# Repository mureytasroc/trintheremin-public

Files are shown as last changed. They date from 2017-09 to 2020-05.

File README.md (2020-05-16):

# TrinTheremin (Version 1)
***




---
#### Important Notes -- Read Before Use
* The minimum case material that the board should have when being played or programmed is the top panel.   After you sodder on the sliders use bolts (provided) to secure the top panel (provided for Advanced CS1) onto the board.   Then when you are using the board hold it by the top laser cut panel, not by the board.

* This version (and all versions) are best used with a full case and horn (see the [case folder](Case) and the [horn folder](Horn) ) for ergonomics and sound quality, though the case and horn are not necessary for basic use.

* The circuit will not work properly if the battery is depleted (see [battery section](#battery) below).   If you have been using the same battery for a while or the circuit is acting like it is low on battery (see [battery section](#battery) below), then follow the instructions in the [battery section](#battery) of this readme to measure how much battery is left.   In future versions there will be an onboard battery sensor you can access in your code.

* The board behaves like an Arduino Micro.   See the "Programming" section below.

* When programming the slider to control the volume of the speaker, map your analog reading from 0-1000 to 0-10.   If you use 0-1023 the full volume tones will sound distorted because it will flicker between volume level 9 and 10.

* See the [example code](#example-code-notes) section of this readme on how to conduct the board calibration.

* See the [expanded documentation](#expanded-documentation) for more information on the board as well as expanded procedures and notes.

---
### Expanded Documentation
---
#### About the Circuit
TrinTheremin, like the Sparkfun <a href="https://www.youtube.com/watch?v=2zZkeeQr49g" target="_blank">Digital Sandboxes</a> used in CS1/CS2, is an all in one programmable <a href="https://learn.sparkfun.com/tutorials/what-is-a-circuit" target="_blank">circuit</a> that allows the user to process/control different inputs/outputs on the board.   Its <a href="http://www.atmel.com/Images/Atmel-7766-8-bit-AVR-ATmega16U4-32U4_Datasheet.pdf" target="_blank">ATMEGA microcontroller chip</a> has its own CPU (central processing unit; the brain of the device), flash memory (where your program is stored), SRAM (where the sketch creates and manipulates variables while running), and <a href="http://tronixstuff.com/2011/03/16/tutorial-your-arduinos-inbuilt-eeprom/" target="_blank">EEPROM</a> (NON-VOLATILE storage space programmers can access/use; EEPROM will keep its stored data even without electrical power (when the unit is off), as opposed to volatile memory (like SRAM) that would lose its data without electrical power).   While you probably won't need to use any EEPROM for this project (although feel free to <a href="https://learn.adafruit.com/memories-of-an-arduino/eeprom" target="_blank">do</a> so if you have a use for it), you will constantly be using the CPU and SRAM, as well as the flash memory (where your program lives).   See this chart for how much memory the microcontroller on the TrinTheremin (the ATMEGA 32u4) has of each main type (there are other memory types onboard that I won't go into):

| Memory Type:  | Amount of storage (bytes): |
| --- | --- |
| Flash  | 32000  |
| SRAM  | 2500  |
| EEPROM  | 1000  |

The flash is not all available, however, as the board's "bootloader" (the software that allows you to upload Arduino code) takes up about 4kB, or 4000 bytes, leaving about 28kB usable for storing code.   The bootloader is already installed on all the boards.

Beyond the chip (and its dedicated hardware such as its crystal and resistors and capacitors), all the circuits on this board should be pretty familiar (with the exception of the speaker's circuit).   See the <a href="https://github.com/TrinitySchoolComputerScience/TrinTheremin/tree/master/Circuit%20Design/Design%20Pictures" target="_blank">circuit design pictures</a> folder.   On the <a href="https://github.com/TrinitySchoolComputerScience/TrinTheremin/tree/master/Circuit%20Design/Design%20Pictures/Schematic/Close%20Ups/Left%20Side%20(Arduino)" target="_blank">left side</a> of the schematic is all the dedicated Arduino hardware, however the <a href="https://github.com/TrinitySchoolComputerScience/TrinTheremin/tree/master/Circuit%20Design/Design%20Pictures/Schematic/Close%20Ups/Right%20Side%20(Peripherals)" target="_blank">right side</a> shows the circuits for all the peripherals (the buttons, switch, light sensor, LEDs, etc).   Take a look at the right side to see how simple (and common) the circuits behind the peripherals are.   The circuit for for the switch, for instance, just includes the switch and a <a href="https://playground.arduino.cc/CommonTopics/PullUpDownResistor" target="_blank">pulldown resistor</a> (which keeps the voltage at 0V unless the switch is closed to 5V) and is connected to a digital pin (D12):

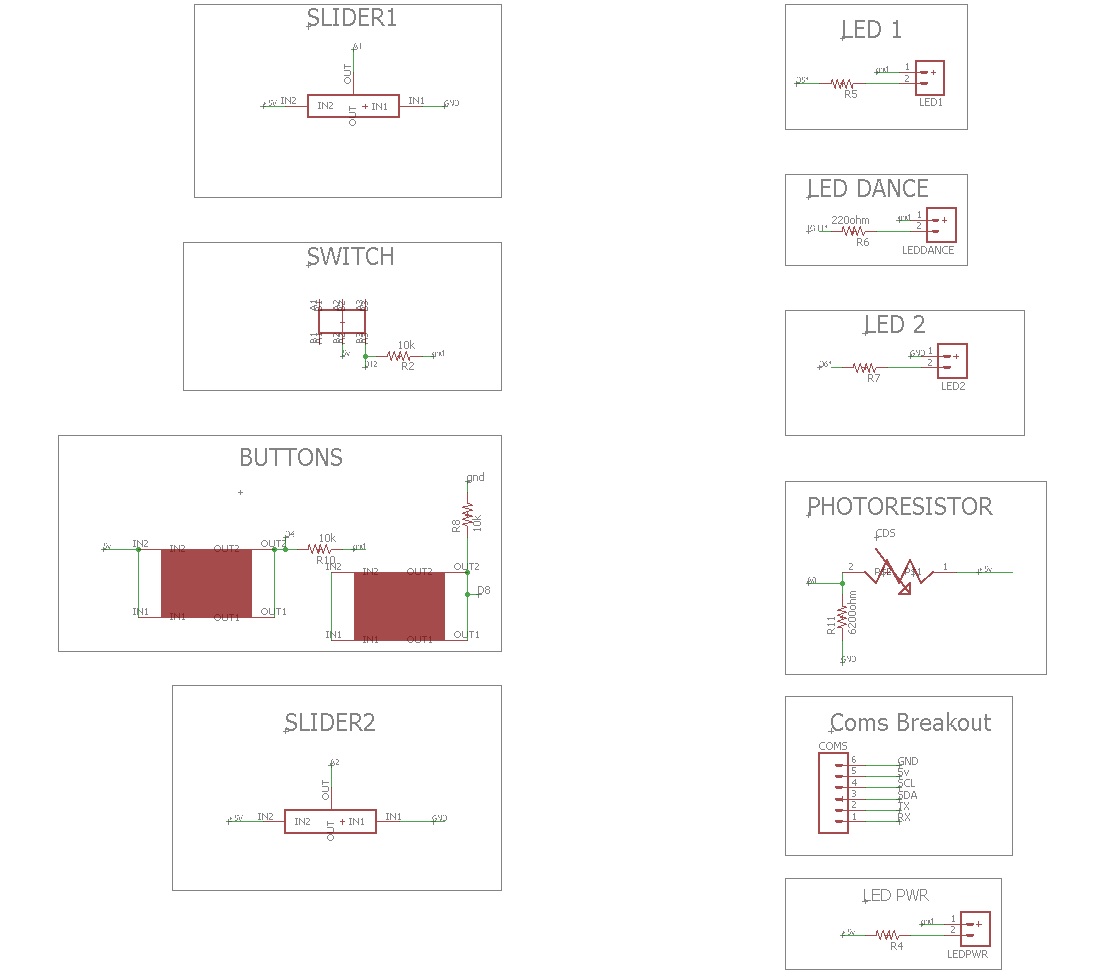
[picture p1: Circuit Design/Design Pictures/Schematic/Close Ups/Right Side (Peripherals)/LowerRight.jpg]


---

#### Usage
The TrinTheremin was purpose built for Trinity's CS2 and Advanced CS1 programs (specifically the physical computing and digital logic units, respectively), although it could be used in a wide variety of applications that use inputs and outputs involving sound and light.

###### Battery
The TrinTheremin's battery should be connected to the 9v battery connector on the bottom of the board and stored in the clip under the slider (also on the bottom of the board).  



Like any device, the TrinTheremin will eventually run out of battery.   Trinity's collection of Apex batteries have a 595mAh capacity.   Milliamp hours (mAh) are a unit of electrical charge (one milliamp hour is about 3.6 coulombs, a unit commonly taught in Trinity physics that is generally used when working with static electricity rather than circuits).   This means that the batteries can supply 595 mA of current for one hour. The TrinTheremin draws about 400 mA when the speaker is on at full volume so at minimum the TrinTheremin will run for about 1.5 hours (with everything running and its speaker on at full volume) continuously.   If you do not have the speaker on the device draws only about 25 mA, which will yield about a day of continuous use (so do not feel the need to turn off the device while programming it as having it on does not use up much battery life) To more accurately determine how much battery life the device has left (and without keeping track of how much time you have used it for), you can measure the remaining battery life with a multimeter (located in the top drawer in the drawers by the door in the computer science lab -- ask Mr. Rose or Mr. Gohde if you are unsure where this is) and a few quick calculations.



First, set the multimeter to measure DC voltage and make sure the leads are connected to the right ports (red to positive (+) and black to negative (-, sometimes referred to as COM) -- see this <a href="https://learn.sparkfun.com/tutorials/how-to-use-a-multimeter" target="_blank">tutorial on multimeters</a>.   Then measure the voltage of the battery (touching the red lead of the multimeter to the positive terminal of the battery (marked by the + symbol on the battery) and the black lead to the negative terminal (marked by the -).   Here is a chart that shows the battery life estimates for an alkaline cell:

| Alkaline Voltage Level and Range (V):  | Usability: |
| --- | --- |
| 1.50  | New and unused  |
| 1.35 – 1.49  | Good  |
| 1.20 – 1.34  | Average  |
| 1.10 – 1.19  | Low  |
| 0.90 – 1.09  | Very Low  |
| < 0.90  | Dead – Discard!  |

Given that alkaline 9v batteries (Trinity's Apex 9v batteries are alkaline) are 6 alkaline cells, we can multiply through these ranges to find voltages that apply to the reading from the 9v battery:

| 9v Battery Voltage Level and Range (V):  | Usability: |
| --- | --- |
| 9  | New and unused  |
| 8.1 – 8.94  | Good  |
| 7.2 – 8.04  | Average  |
| 6.6 – 7.14  | Low (Unusuable below about 6.75v)|
| 5.4 – 6.54  | Very Low (Unusable)|
| < 5.4  | Dead – Discard! (Unusable)|

There is one more factor to consider, though, and that is that the TrinTheremin needs about 6.75v to run properly.   This is because the voltage regulator (a chip on the board that takes the voltage being supplied by the battery and regulates it at a constant 5v for the circuit to use) needs at least 6.75v to be able to output 5v as its supposed to.   This extra 1.75 volts it needs is called the "dropout voltage" -- this chart from the chip's <a href="http://www.st.com/content/ccc/resource/technical/document/datasheet/41/4f/b3/b0/12/d4/47/88/CD00000444.pdf/files/CD00000444.pdf/jcr:content/translations/en.CD0000044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" target="_blank">datasheet</a> was how I found that the dropout voltage is 1.75 volts (assuming 25C temperature and 500mA current draw):



If the board is acting weird or blatantly executing programming commands incorrectly (that's not because of mistakes in the code) it is almost certainly because its does not have the necessary voltage (so measure it and replace the battery if necessary). There is a small range of voltages where the board will turn on but may work improperly.   

###### Programming
The TrinTheremin has the same chip as an <a href="https://store.arduino.cc/usa/arduino-micro">Arduino Micro</a>, so it will behave almost identically to that board.   Important caveats to note:
* When using Serial (rx/tx) on the "COM breakout" you must use Serial1 instead of Serial.   Since this chip has its own embedded usb circuit, Serial.print will print to the Arduino console as usual, however Serial1 will reference the hardware serial ports (rx/tx). So you would use Serial1.begin(9600), Serial1.print("text"), etc to use the HARDWARE serial.   On an Arduino Uno, for example, which has an external USB circuit that is connected inline with the hardware serial ports, the Serial command references both the hardware and the usb serial (so Serial.print will output serial on the tx port but also print to the Arduino developer's console)

* Because the chip has built in USB, when you plug it into your computer it will be recognized as a mouse or keyboard (and you can actually use it as such -- more on that <a href="https://www.arduino.cc/en/Reference/MouseKeyboard">here</a>).

* When you upload your code, select "Arduino Micro" under boards, and the appropriate port under ports.

-----

###### Example Code Notes

* When programming the slider to control the volume of the speaker, map your analog reading from 0-1000 to 0-10.   If you use 0-1023 the full volume tones will sound distorted because it will flicker between volume level 9 and 10.

* The calibration procedure in the example code is this: 
  i. When one LED is blinking do not cover the sensor at all -- it is measuring the ambient light levels; 
  ii. Once the speaker makes a noise and the LED stops blinking cover the sensor with your hand
  iii. Once both LEDs stop blinking and then light up in a pattern the calibration process is complete

* The autoplay feature can work very well if you put your hand over the dancing LED and the sensor.   It will work fine if you leave it in ambient light, but the more ambient light there is, the worse it will work (this cannot be fixed in calibration -- think about it like the LED's light is getting drowned out).

* The toneAc library is used to control the speaker.   To download toneAc see this <a href="https://bitbucket.org/teckel12/arduino-toneac/wiki/Home">link</a>.   Here is the toneAc <a href="https://playground.arduino.cc/Code/ToneAC">reference</a>.

-------
#### Plans for future versions
If any future versions of the TrinTheremin are produced these are some of the goals that did not get included in this initial version:

* _A more efficient amplifier_ -- the amplifier circuit on the TrinTheremin right now is very simple to use and understand (both in software and in hardware), works with the ToneAC library, and has pretty good quality sound (meeting the goals of the board).   However in future versions a more sophisticated amplifier circuit might be combined with a possible TrinTheremin Arduino library to keep the software simplicity of ToneAC while improving quality and GREATLY improving efficiency (battery life would be improved immensely).

* _A voltage divider circuit_ -- this is one of the easiest (and also most helpful) changes that could be introduced in future versions.   Essentially this would take the voltage of the battery, divide it in two (9v becomes 4.5, 7 becomes 3.5, etc), and feed it to an analog input (0v-5v yields a 0-1023 reading) on the microcontroller.   This would allow the programmer to measure the voltage of the battery.   With this they could create an integrated battery life check that would alert the user if the battery were low.

* _Headphone jack_ -- a headphone jack could be added to the board in addition to the speaker so the user could play with headphones on.   The port would have a switch in it that would be conencted to a digital pin so the programmer could automatically turn off the speaker when headphones are plugged in.

* _Reduced cost_ -- right now the TrinTheremin costs about 25$ per board to produce, however with hardware changes and different production methods, this could potentially be significantly reduced.   For reference an Arduino Micro costs about 22$ (with no inputs or outputs built in)

* _Expanded documentation and a more seamless user interface -- maybe a website?_ -- Right now trintherem.in redirects to this github repository, however in the future a website dedicated to the TrinTheremin could be produced.

----

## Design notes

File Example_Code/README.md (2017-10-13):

# Using the TrinTheremin

## Basic Steps
1. **Plug the board into a USB port**. If you want to use the TrinTheremin on battery power: plug in a battery (see home page readme), and turn it on with the power switch.
2. **Calibrate the TrinTheremin**. When the unit first turns on, hold the board normally to allow the sensor to read the ambient light level.   Once the board makes a sound, place your hand over the sensor so it can read a low value.   When the two LEDs stop blinking and flicker the calibration is complete.
3. **Play the TrinTheremin**. Be sure to avoid touching the underside of the board. The amplifier cicuit for the speaker can get hot.

## Learning Activities
1. Experiment with the other switches, sliders, buttons, and LED's on the TrinTheremin. What is the purpose of each? Hand-draw a diagram of the top of the TrinTheremin. 
   - Label all of the TrinTheremin components used for input/output.

2. Examine the code contained in *TrinThereminExampleCode.ino*. This is the code that controls the behavior of the TrinTheremin. It is written in the Arduino programming language because the TrinTheremin essentially embeds an Arduino Micro into a custom circuit board. 
   - Label each component on your hand-drawn diagram with both the pin number and identifier name given to it in *TrinThereminExampleCode.ino*

3. Add two octaves of F Major as a new scale.
   - First, add F Major by replacing the G scale.
   - Then, add back the G scale and incorporate F Major as a fifth option.
   
4. Find the Circuit Design picture of the BoardTop and the BoardBottom.
   - What do the green markings indicate?
   - What do the red markings indicate?
   - What do the white markings indicate?
   - What do the blue markings indicate?

To-Do:
--------------
- Pure max/min for calibration

- Quantized playing (for the non-sequential note problem)

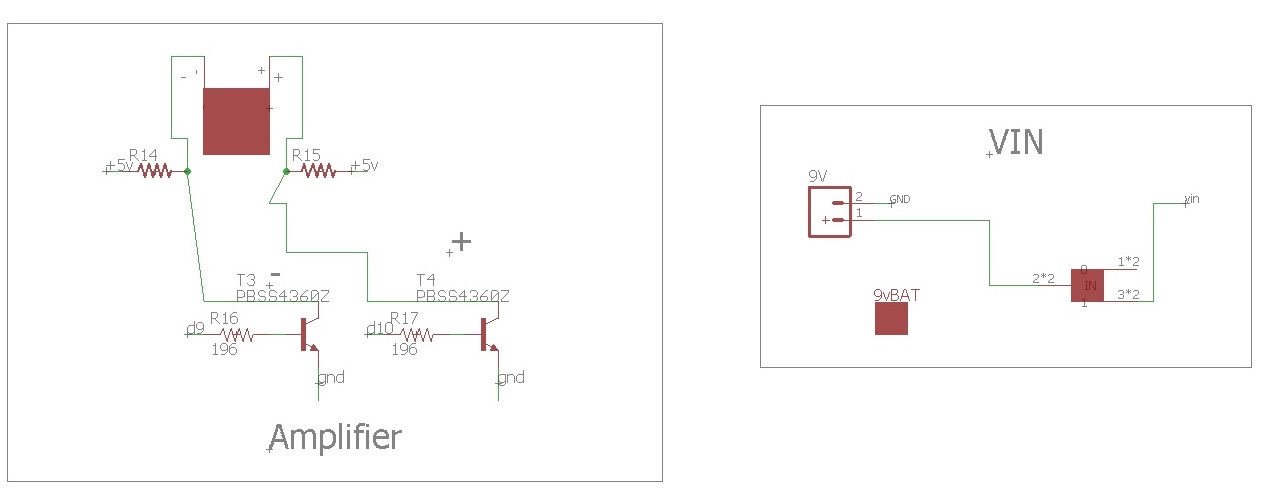
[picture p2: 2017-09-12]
Circuit_Design/Design Pictures/Schematic/Close Ups/Right Side (Peripherals)/UpperRight.jpg

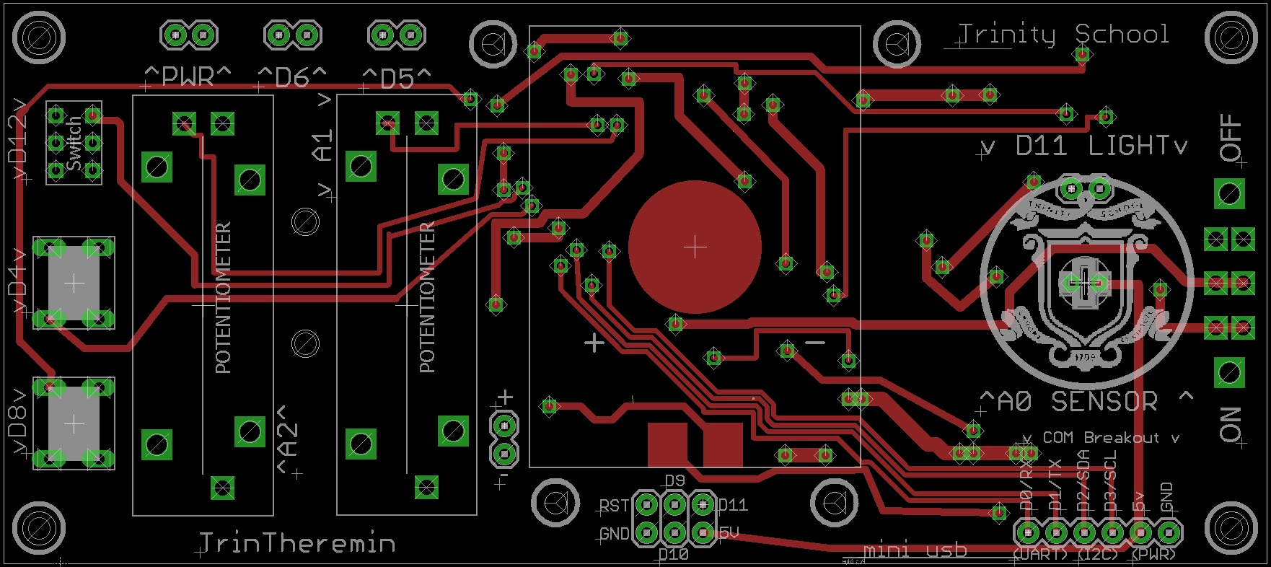
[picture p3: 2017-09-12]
Circuit_Design/Design Pictures/Board/BoardTop.jpg

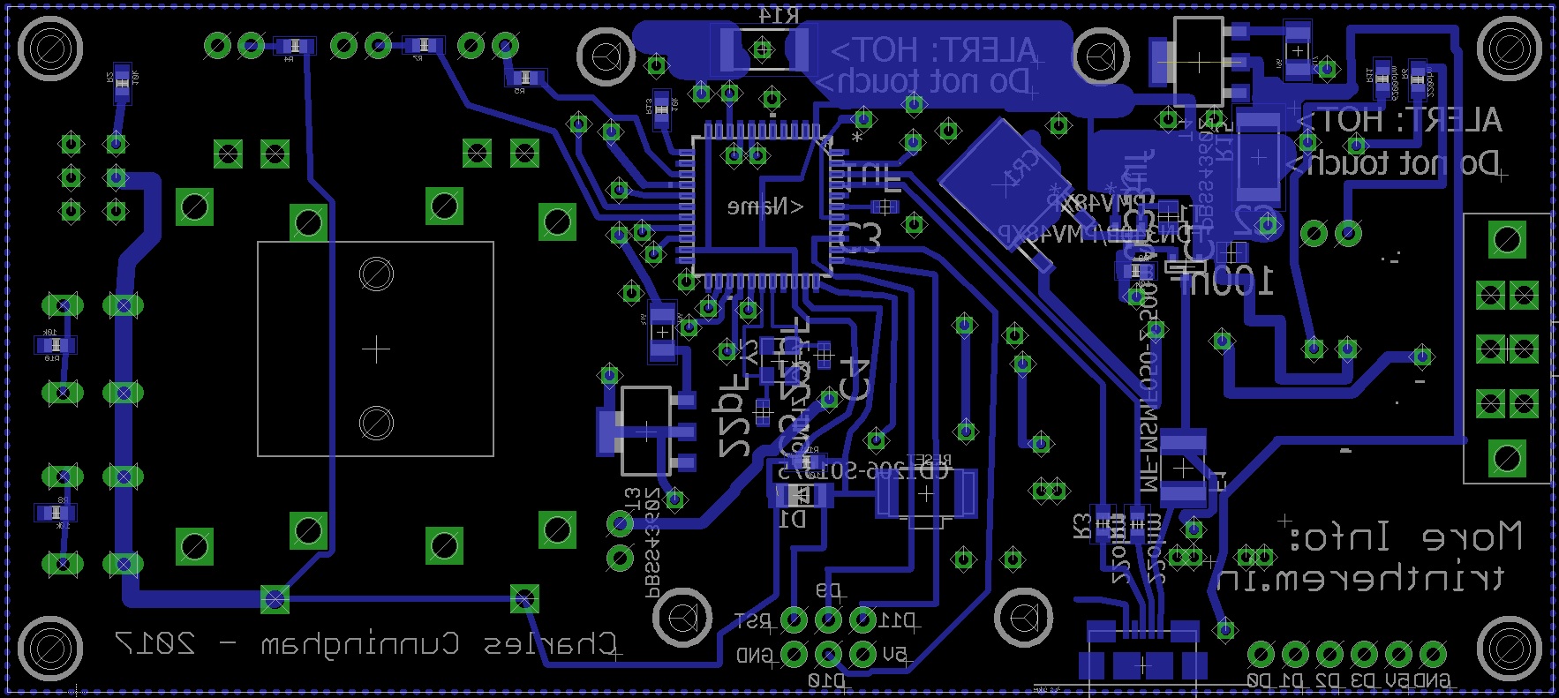
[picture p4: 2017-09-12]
Circuit_Design/Design Pictures/Board/BoardBottom.jpg

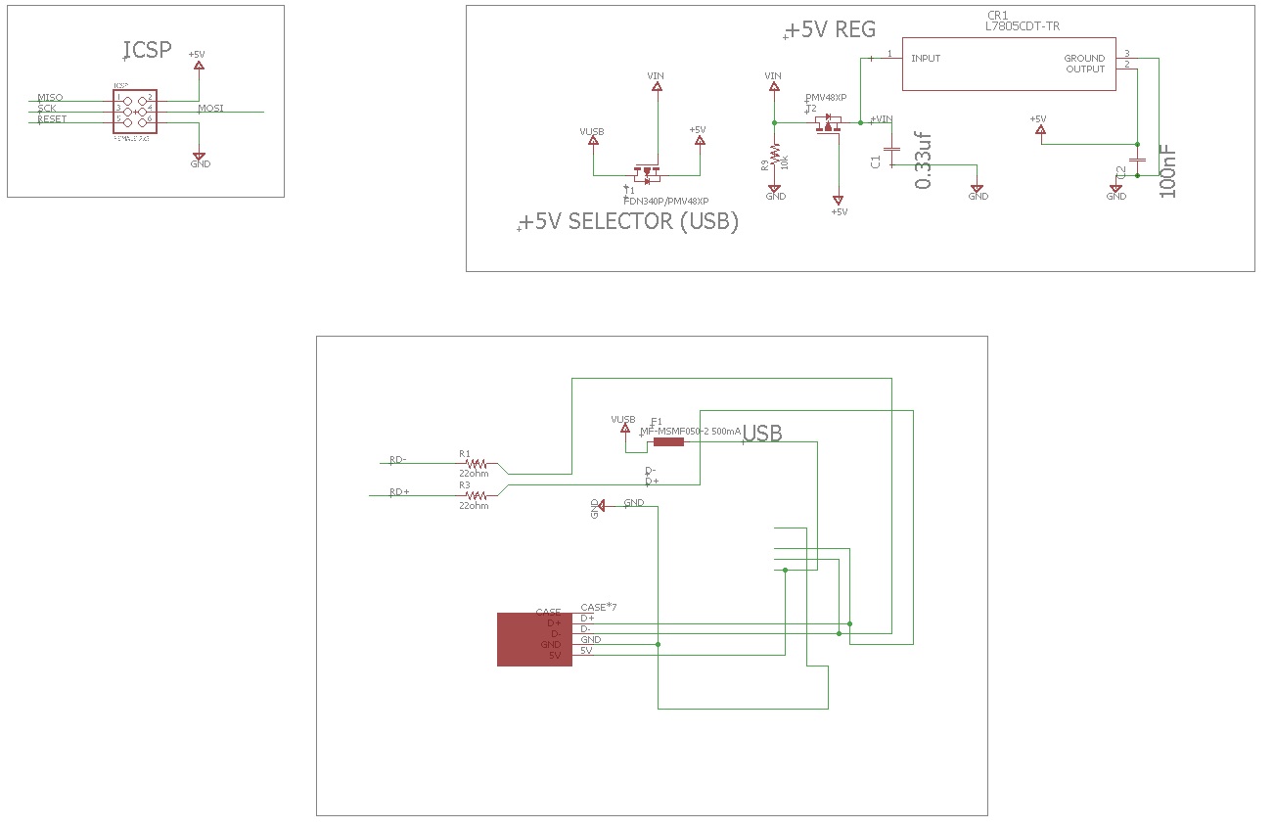
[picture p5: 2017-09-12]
Circuit_Design/Design Pictures/Schematic/Close Ups/Left Side (Arduino)/LowerLeft.jpg

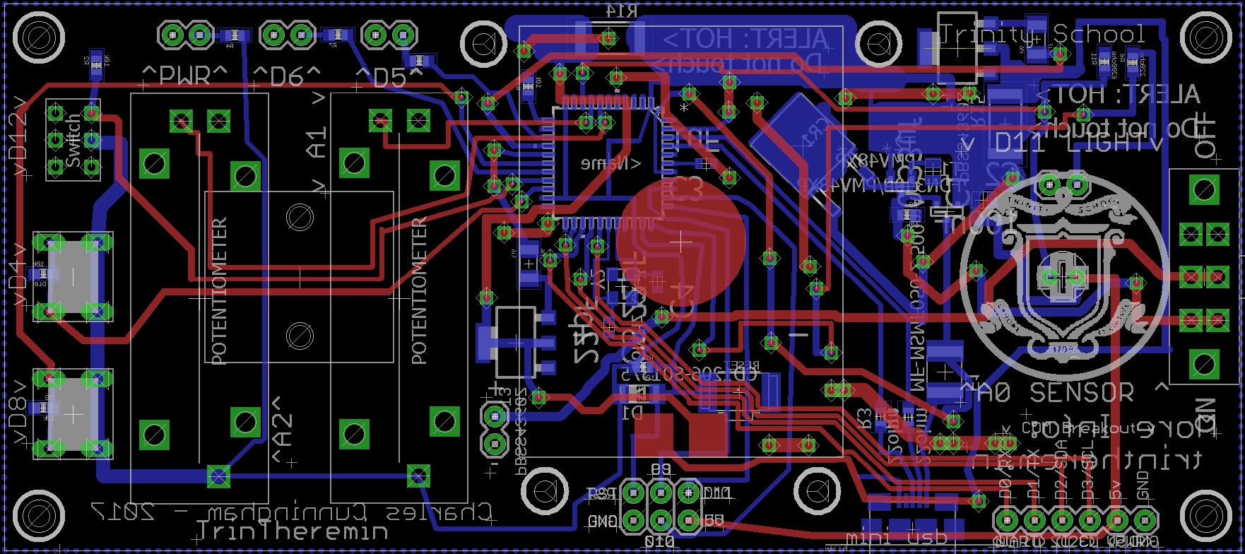
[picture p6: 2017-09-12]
Circuit_Design/Design Pictures/Board/BoardFull.jpg

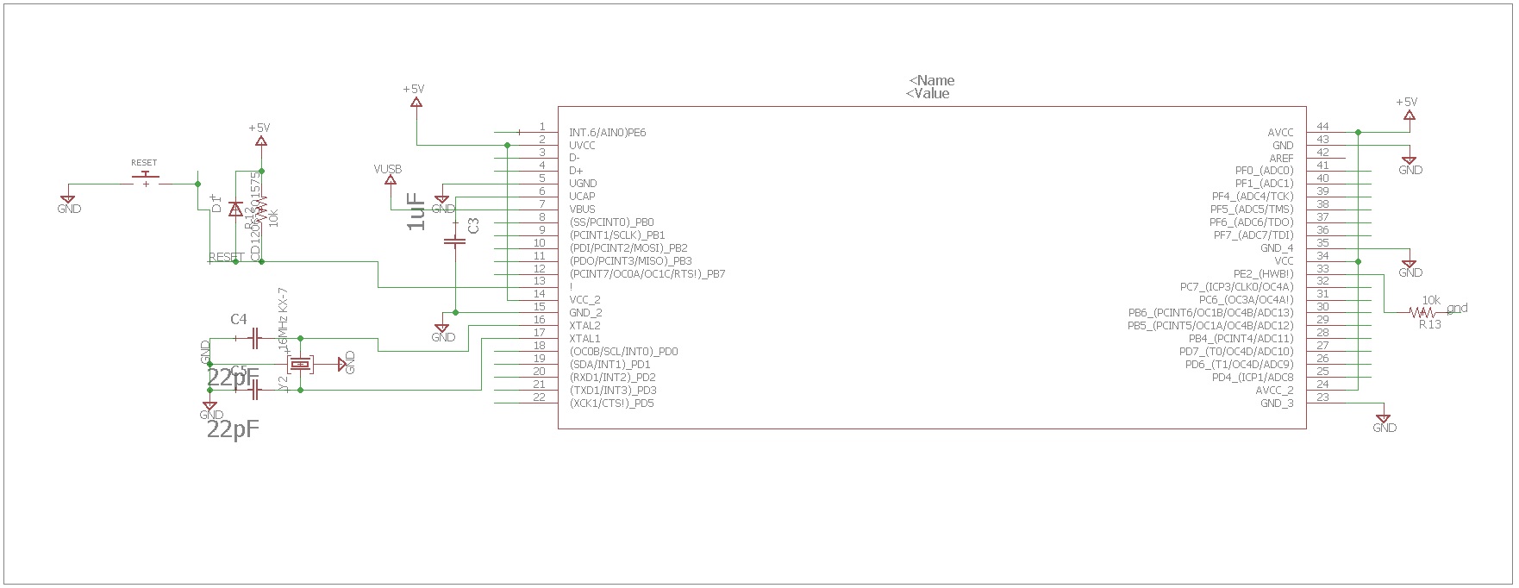
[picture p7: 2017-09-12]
Circuit_Design/Design Pictures/Schematic/Close Ups/Left Side (Arduino)/UpperLeft.jpg

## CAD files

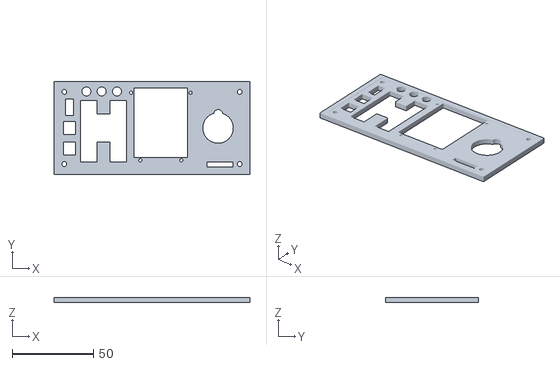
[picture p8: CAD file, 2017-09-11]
Case/3D Design Files/Case STL (3D Models)/CaseTopExample.STL
120.6 x 57.1 x 3.30

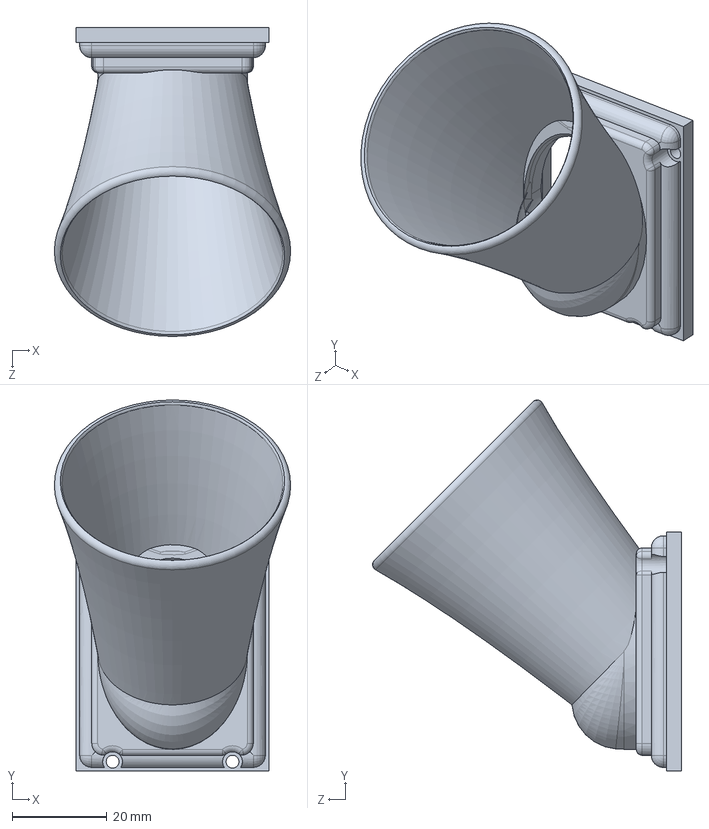
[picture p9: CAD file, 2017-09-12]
Horn/Solidworks/Example/HornExampleMK1.SLDPRT
49.8 x 78.1 x 65.1 mm

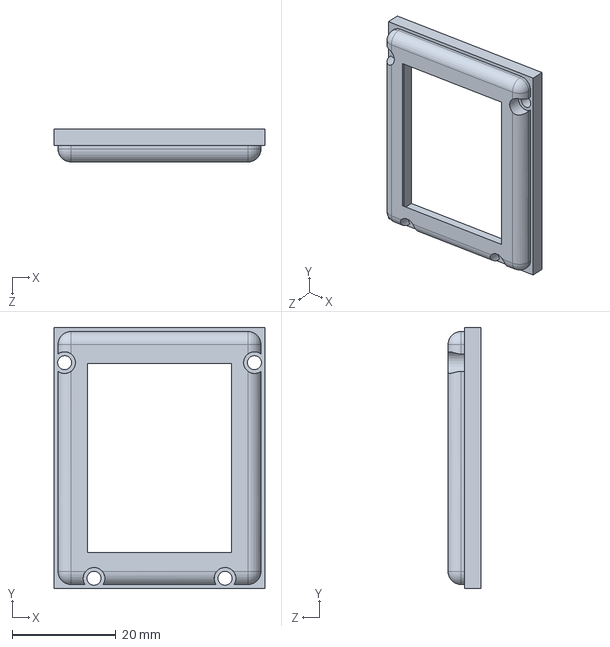
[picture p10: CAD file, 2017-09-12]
Horn/Solidworks/Horn Base/HornBase.SLDPRT
40.6 x 50.3 x 6.35 mm

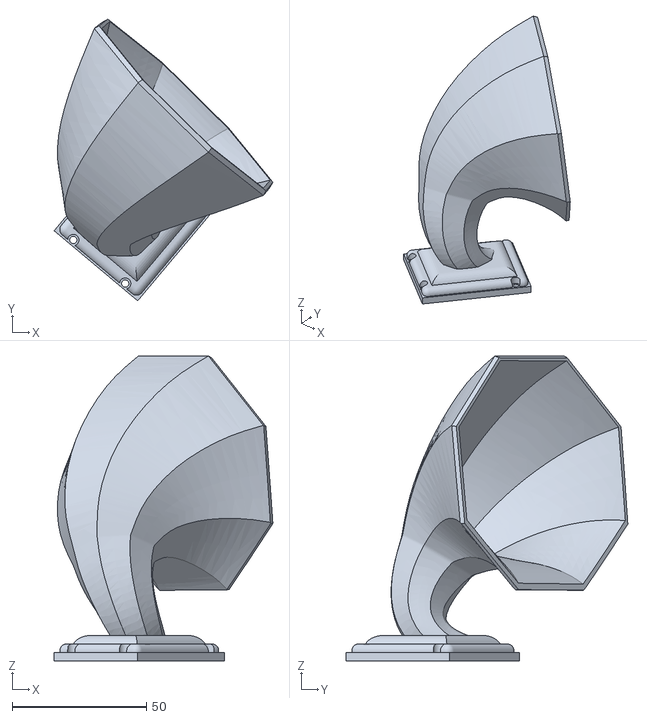
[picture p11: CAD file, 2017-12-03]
Horn/STL files (Recommended)/Example/HornExampleMK2.STL
81.5 x 105.0 x 113.6

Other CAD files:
Case/3D Design Files/Solidworks Files/CaseTopExample.SLDPRT
Horn/STL files (Recommended)/Horn Base (Recommended)/HornBase.STL
Case/3D Design Files/Solidworks Files/CaseTopSketch.SLDPRT
Horn/Solidworks/Horn Base/HornSketch.SLDPRT
Horn/STL files (Recommended)/Example/HornExampleMK1.STL

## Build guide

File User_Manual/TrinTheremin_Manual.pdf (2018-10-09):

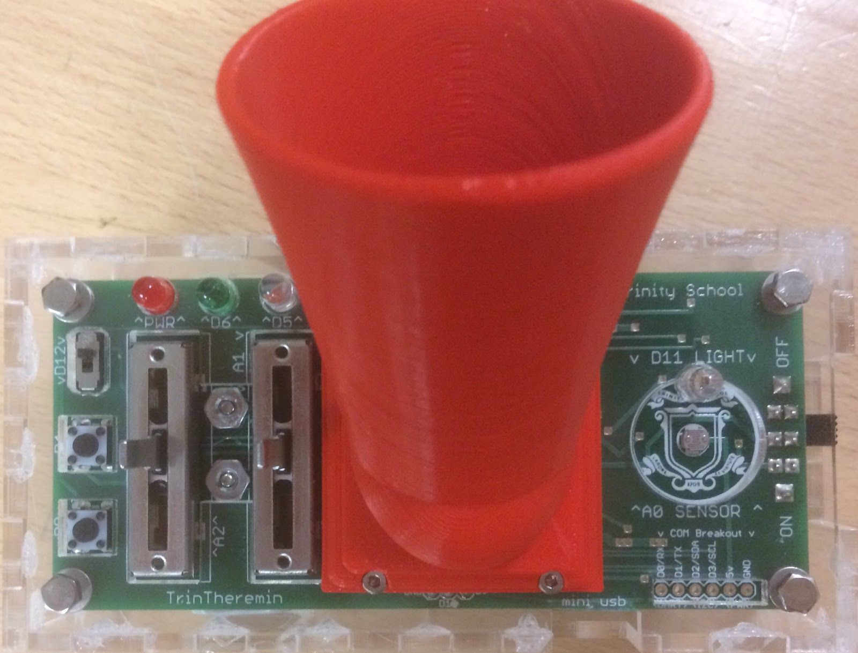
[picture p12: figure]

# TrinTheremin

### Version 1.0

Last modified 12/20/17
─

## Trinity School

### Computer Science

Developed by Charles Cunningham in 2017
With help and guidance from Mr. Gohde, Mr. Rose, and Mr. Schober

# About

The TrinTheremin is a project inspired by the curriculum of Trinity’s second semester CS2 and first semester Advanced CS1 courses. These courses are part of Trinity’s four year computer science program. The specific unit that this project grew from challenged students to make an “opto-theremin”. A theremin is a musical instrument that can be played without making contact with the device. Originally invented in 1928 by a Soviet inventor named León Theremin, a theremin uses the capacitive properties of the human body to manipulate sound with the distance of the user’s hand from the device. An “opto-theremin” is a similar device that uses light instead of capacitance to manipulate sound. It is played very similarly to the theremin, by moving one’s hand farther or closer away from the sensor on the device (and thus varying the amount of light exposed to the sensor) to change its pitch.

The TrinTheremin was developed to address a substantial drawback of this unit; unlike software projects, students’ opto-theremin projects were physically made on temporary circuit testing and prototyping platforms called “breadboards”. After students finished making their circuits, they could keep their code but had to disassemble their projects, essentially throwing away all their hard work. The TrinTheremin is a platform that integrates what is known as a “microcontroller” chip to allow students to upload their code (with a few modifications) onto the device and play the instrument that they designed on a permanent and sound-amplified system. Another benefit of using the TrinTheremin is that it is much more ergonomic than a circuit made on a breadboard and can be played much more easily. Although the circuits designed by students vary greatly, the TrinTheremin has a wide variety of control inputs (sliders, buttons, switches, expansion pins) to cover nearly anything a student might want to include in their design. To translate their code to work with the TrinTheremin students only have to change the addresses of the control inputs used in their old circuit to the ones in the TrinTheremin.

With the help of some of Trinity’s circuit design facilities (the “Othermill” circuit board mill, the infrared circuit board oven, and the laser cutter) I was able to produce and test a number of different prototypes of the TrinTheremin until we settled on a final design for version 1.0. Version 2 is in the works, with the possibility of a more efficient amplifier circuit, a headphone jack so multiple students can play the devices without generating too much noise pollution, a battery level sensor so that the circuit can monitor its own battery level and other subtle additions and design changes. See the “Plans for future versions” page for more information on version 2.

# Acknowledgements

This project could not have come this far without the help of a few people. I would like to firstly thank Mr. Gohde and Mr. Rose for sponsoring this project and giving help and advice throughout the process. I would like to thank Mr. Schober and Mr. Rose who worked with me to develop a new way of making circuit board stencils with a laser cutter, allowing me to spread solder paste on boards easily and precisely. With the solder paste laid down I could bake the boards in Trinity’s modded (for better performance) infrared IC oven to attach surface mounted components. This new technique took a process that normally takes days down to less than an hour, significantly helped the TrinTheremin prototyping process, and will make circuit board production much easier for students in the future. I would like to thank Mr. Gohde for helping to improve the example code and take the project to another level of performance and usability. Furthermore, his constant openness to push and improve projects, rather than just accepting things as “good enough” have really taken this project from a simple hastily put together arduino shield to what it is today. I would like to thank the students of the class of 2019 and current Advanced CS students who have given me invaluable feedback, tips, and ideas. Finally I would like to thank Trinity School for supporting the Computer Science and Robotics programs, without which none of this would have happened.

# Example Code Quick Start Guide

1. General Controls and Layout:
a. The switch on the right side of the board is the power button. If the battery is connected and the switch is in the on position the board will turn on. You can also power the board by connecting a micro USB cable to the USB port. The board will automatically pull power from the USB port if both a battery and a USB cable are connected.
b. The red light at the top right is the power light (always on when there is power to the board).
c. The green (D6) and blue (D5) lights will be used in the calibration sequence. In normal playing the green light will be on permanently and the blue light will reflect the pitch of the note that you are playing.
d. The light sensor that you will wave your hand above to play the device is the round white and gold piece above the Trinity logo on the right side of the board (A0).
e. The rightmost slider on the left side of the board (A1) controls volume (down is louder).
f. The left slider (A2) controls the scale of notes you are playing (Major C, Pentatonic, G, etc). There are four different scales loaded onto the board by default and the note that is being played in the scale selected by the slider depends on the amount of light on the sensor.
g. The switch in the top left corner of the board (D12) turns the audio on and off. The blue light will turn off if you switch the audio off.
h. The topmost button (D4) will turn on the autoplay feature when pressed. The dancing LED next to the sensor will turn on and the device will play itself, if you follow the autoplay procedure detailed in step #6.
i. The bottom button (D8) will pause the audio when pressed. If you want to play two notes of the same pitch you can tap this button to separate the notes.
2. Upon turning on the device you need to calibrate it so that it knows the ambient light levels. It starts the calibration sequence immediately, so right after you turn the board on wave your hand up and down slowly and constantly. To set the board’s minimums and maximums your hand should go from completely covering the sensor to exposing it to full ambient light. After about 5 seconds the lights will flicker indicating that the calibration sequence is complete.
3. Finally, now that you are in play mode, the green light (D6) should be illuminated. Turn up the volume and if the device is not making sound, switch the audio on (D12). Once it is playing the highest note in the selected scale will be played when the sensor is exposed to full ambient light and the lowest note will play when your hand is covering the sensor. Vary the height of your hand above the sensor to hit all the notes in the scale.
4. If you hear a clicking sound the volume slider is probably in between two values. Change its position a little bit and this should go away. Two notes can also be blended if your hand is hovering right between them. The device uses a smoothing algorithm to make this blending a little less erratic. As you play the device more you will get the hang of how to avoid and/or take advantage of this characteristic.
5. Finally, you should keep track of battery life. In the next version the circuit will be able to monitor its own battery level but for this one you should just keep a rough estimate of how long you have played it. A fresh 1200mah battery will last 3-6 hours of cumulative audio output. 3 hours at full volume, 6 hours at half volume, much longer at low volumes. If you start to approach these values and the device starts behaving abnormally the battery should be changed. The battery is kept in the metal clip on the bottom of the board.
6. The autoplay feature of the TrinTheremin is designed to work best with lower ambient light levels. If the autoplay light is turned on in a bright room, the dancing LED will not make much of a brightness difference to the sensor, and the autoplay feature will not work well. Therefore, it is recommended that you put your hand an inch or so above the dancing LED and sensor on the Trinity logo before turning on the autoplay feature. The exact height of your hand above the sensor does not matter as the code will sense the ambient light conditions with your hand over the device and account for it appropriately. When you turn it on it runs through a very brief (unnoticeable) calibration procedure that senses the ambient light levels with your hand over the sensor. Every time you turn on the autoplay feature it will calibrate to wherever your hand is, but will not adapt if you move your hand while the autoplay feature is running (while you are holding down the autoplay button).

# Expanded Documentation

About the Circuit

TrinTheremin, like the Sparkfun Digital Sandboxes (https://www.youtube.com/watch?v=2zZkeeQr49g) used in CS1/CS2, is an all in one programmable circuit (https://learn.sparkfun.com/tutorials/what-is-a-circuit) that allows the user to process/control different inputs/outputs on the board. Its ATMEGA microcontroller chip (http://www.atmel.com/Images/Atmel-7766-8-bit-AVR-ATmega16U4-32U4_Datasheet.pdf) has its own CPU (central processing unit; the brain of the device), flash memory (where your program is stored), SRAM (where the sketch creates and manipulates variables while running), and EEPROM (http://tronixstuff.com/2011/03/16/tutorial-your-arduinos-inbuilt-eeprom/) (NON-VOLATILE storage space programmers can access/use; EEPROM will keep its stored data even without electrical power (when the unit is off), as opposed to volatile memory (like SRAM) that would lose its data without electrical power). While you probably won't need to use any EEPROM for this project (although feel free to do (https://learn.adafruit.com/memories-of-an-arduino/eeprom) so if you have a use for it), you will constantly be using the CPU and SRAM, as well as the flash memory (where your program lives). See this chart for how much memory the microcontroller on the TrinTheremin (the ATMEGA 32u4) has of each main type (there are other memory types onboard that I won't go into):

Memory Type: | Amount of storage (bytes):
Flash | 32000
SRAM | 2500
EEPROM | 1000

The flash is not all available, however, as the board's "bootloader" (the software that allows you to upload Arduino code) takes up about 4kB, or 4000 bytes, leaving about 28kB usable for storing code. The bootloader is already installed on all the boards.

Beyond the chip (and its dedicated hardware such as its crystal and resistors and capacitors), all the circuits on this board should be pretty familiar (with the exception of the speaker's circuit). See the circuit design pictures (https://github.com/TrinitySchoolComputerScience/TrinTheremin/tree/master/Circuit%20Design/Design%20Pictures) folder. On the left side (https://github.com/TrinitySchoolComputerScience/TrinTheremin/tree/master/Circuit%20Design/Design%20Pictures/Schematic/Close%20Ups/Left%20Side%20(Arduino)) of the schematic is all the dedicated Arduino hardware, however the right side (https://github.com/TrinitySchoolComputerScience/TrinTheremin/tree/master/Circuit%20Design/Design%20Pictures/Schematic/Close%20Ups/Right%20Side%20(Peripherals)) shows the circuits for all the peripherals (the buttons, switch, light sensor, LEDs, etc). Take a look at the right side to see how simple (and common) the circuits behind the peripherals are. The circuit for for the switch, for instance, just includes the switch and a pulldown resistor (https://playground.arduino.cc/CommonTopics/PullUpDownResistor) (which keeps the voltage at 0V unless the switch is closed to 5V) and is connected to a digital pin (D12):

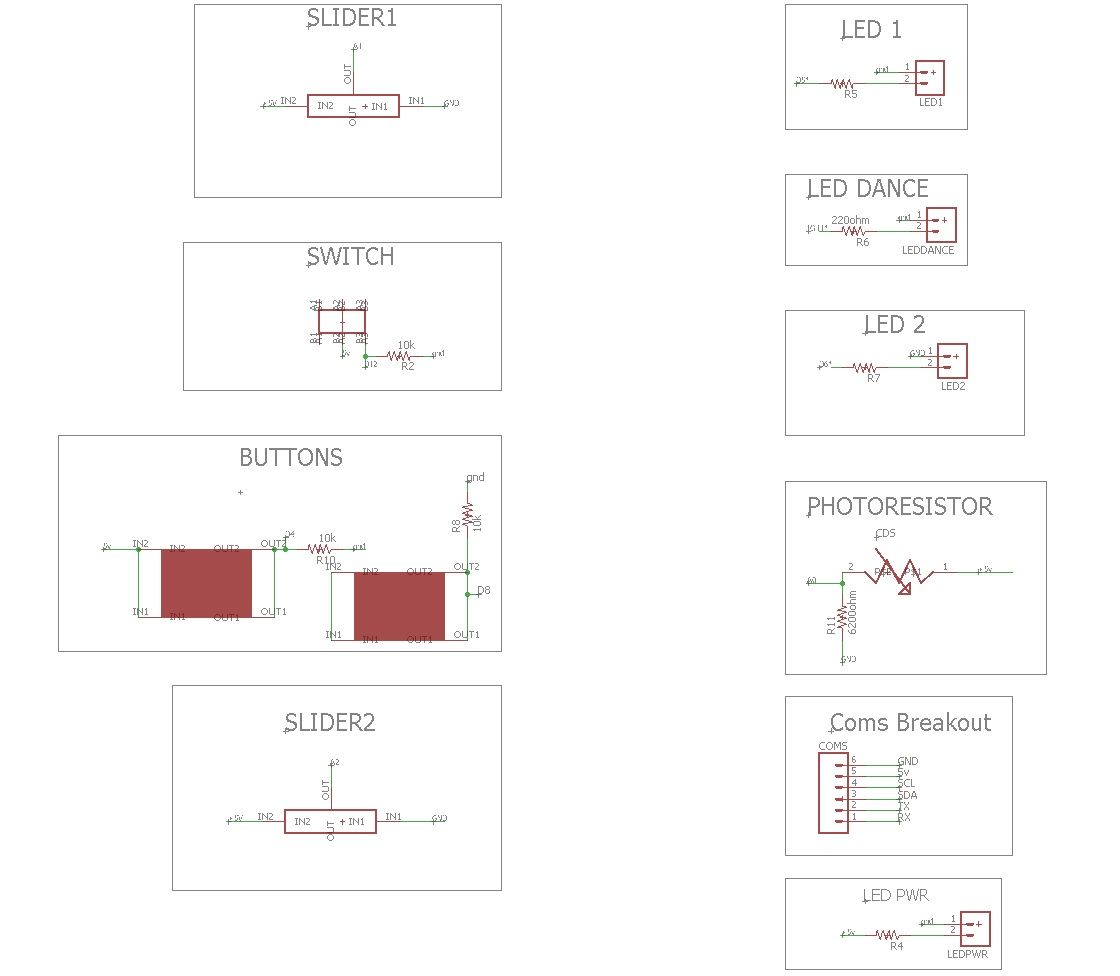
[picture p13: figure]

Usage

The TrinTheremin was purpose built for Trinity's CS2 and Advanced CS1 programs (specifically the physical computing and digital logic units, respectively), although it could be used in a wide variety of applications that use inputs and outputs involving sound and light.

Battery

The TrinTheremin's battery should be connected to the 9v battery connector on the bottom of the board and stored in the clip under the slider (also on the bottom of the board).

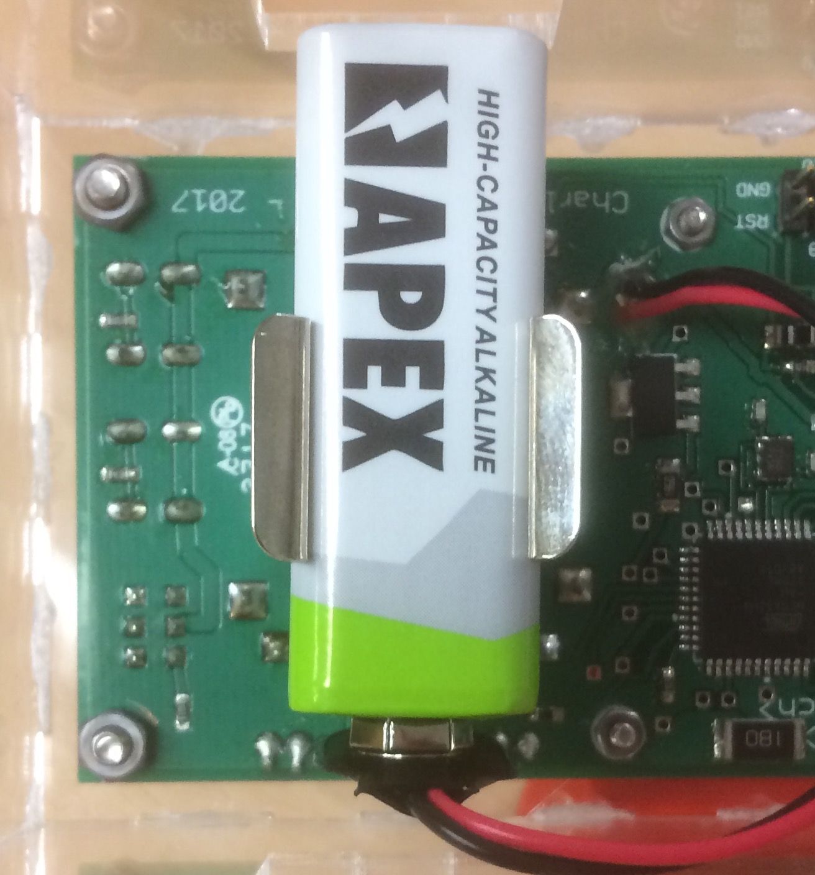
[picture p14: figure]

Like any device, the TrinTheremin will eventually run out of battery. Trinity's collection of Apex batteries have a 595mAh capacity. Milliamp hours (mAh) are a unit of electrical charge (one milliamp hour is about 3.6 coulombs, a unit commonly taught in Trinity physics that is generally used when working with static electricity rather than circuits). This means that the batteries can supply 595 mA of current for one hour. The TrinTheremin draws about 400 mA when the speaker is on at full volume so at minimum the TrinTheremin will run for about 1.5 hours (with everything running and its speaker on at full volume) continuously. If you do not have the speaker on the device draws only about 25 mA, which will yield about a day of continuous use (so do not feel the need to turn off the device while programming it as having it on does not use up much battery life) To more accurately determine how much battery life the device has left (and without keeping track of how much time you have used it for), you can measure the remaining battery life with a multimeter (located in the top drawer in the drawers by the door in the computer science lab -- ask Mr. Rose or Mr. Gohde if you are unsure where this is) and a few quick calculations.

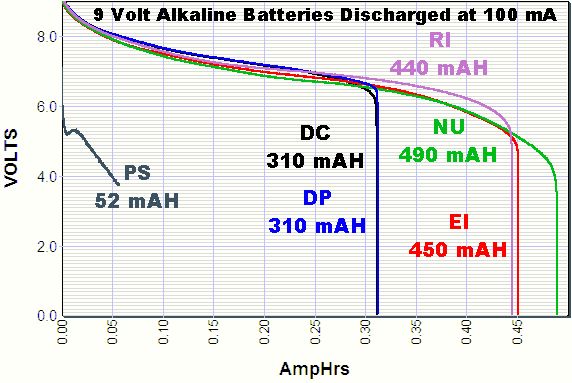
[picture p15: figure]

First, set the multimeter to measure DC voltage and make sure the leads are connected to the right ports (red to positive (+) and black to negative (-, sometimes referred to as COM) -- see this tutorial on multimeters. (https://learn.sparkfun.com/tutorials/how-to-use-a-multimeter) Then measure the voltage of the battery (touching the red lead of the multimeter to the positive terminal of the battery (marked by the + symbol on the battery) and the black lead to the negative terminal (marked by the -). Here is a chart that shows the battery life estimates for an alkaline cell:

Alkaline Voltage Level and Range (V): | Usability:
1.50 | New and unused
1.35 – 1.49 | Good
1.20 – 1.34 | Average
1.10 – 1.19 | Low
0.90 – 1.09 | Very Low
< 0.90 | Dead – Discard!

Given that alkaline 9v batteries (Trinity's Apex 9v batteries are alkaline) are 6 alkaline cells, we can multiply through these ranges to find voltages that apply to the reading from the 9v battery:

9v Battery Voltage Level and Range (V): | Usability:
9 | New and unused
8.1 – 8.94 | Good
7.2 – 8.04 | Average
6.6 – 7.14 | Low (Unusable below about 6.75v)
5.4 – 6.54 | Very Low (Unusable)
< 5.4 | Dead – Discard! (Unusable)

There is one more factor to consider, though, and that is that the TrinTheremin needs about 6.75v to run properly. This is because the voltage regulator (a chip on the board that takes the voltage being supplied by the battery and regulates it at a constant 5v for the circuit to use) needs at least 6.75v to be able to output 5v as it's supposed to. This extra 1.75 volts it needs is called the "dropout voltage" --this chart from the chip's datasheet (http://www.st.com/content/ccc/resource/technical/document/datasheet/41/4f/b3/b0/12/d4/47/88/CD00000444.pdf/files/CD00000444.pdf/jcr:content/translations/en.CD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) was how I found that the dropout voltage is 1.75 volts (assuming 25C temperature and 500mA current draw):

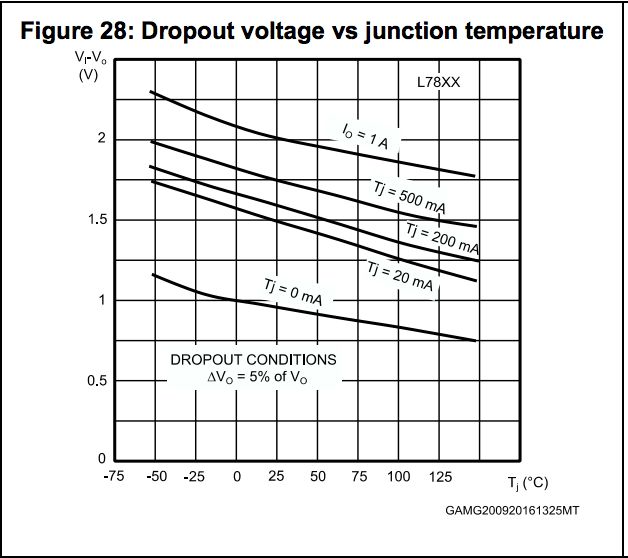
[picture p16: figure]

If the board is acting weird or blatantly executing programming commands incorrectly (if it’s not a problem with the uploaded code) it is almost certainly because its does not have the necessary voltage (so measure it and replace the battery if necessary). There is a small range of voltages where the board will turn on but may work improperly.

Programming

The TrinTheremin has the same chip as an Arduino Micro, (https://store.arduino.cc/usa/arduino-micro) so it will behave almost identically to that board. Important caveats to note:

- When using Serial (rx/tx) on the "COM breakout" you must use Serial1 instead of Serial. Since this chip has its own embedded usb circuit, Serial.print will print to the Arduino console as usual, however Serial1 will reference the hardware serial ports (rx/tx). So you would use Serial1.begin(9600), Serial1.print("text"), etc to use the HARDWARE serial. On an Arduino Uno, for example, which has an external USB circuit that is connected inline with the hardware serial ports, the Serial command references both the hardware and the usb serial (so Serial.print will output serial on the tx port but also print to the Arduino developer's console)
- Because the chip has built in USB, when you plug it into your computer it will be recognized as a mouse or keyboard (and you can actually use it as such -- more on that here). (https://www.arduino.cc/en/Reference/MouseKeyboard)
- When you upload your code, select "Arduino Micro" under boards, and the appropriate port under ports.

Example Code Notes

- When programming the slider to control the volume of the speaker, map your analog reading from 0-1000 to 0-10. If you use 0-1023 the full volume tones will sound distorted because it will flicker between volume level 9 and 10.
- The calibration procedure in the example code is this: i. When one LED is blinking do not cover the sensor at all -- it is measuring the ambient light levels; ii. Once the speaker makes a noise and the LED stops blinking cover the sensor with your hand iii. Once both LEDs stop blinking and then light up in a pattern the calibration process is complete
- The autoplay feature can work very well if you put your hand over the dancing LED and the sensor. It will work fine if you leave it in ambient light, but the more ambient light there is, the worse it will work (this cannot be fixed in calibration --think about it like the LED's light is getting drowned out).
- The toneAc library is used to control the speaker. To download toneAc see this link. (https://bitbucket.org/teckel12/arduino-toneac/wiki/Home) Here is the toneAc reference. (https://playground.arduino.cc/Code/ToneAC)

Plans for future versions

If any future versions of the TrinTheremin are produced these are some of the goals that did not get included in this initial version:

- A more efficient amplifier -- the amplifier circuit on the TrinTheremin right now is very simple to use and understand (both in software and in hardware), works with the ToneAC library, and has pretty good quality sound (meeting the goals of the board). However in future versions a more sophisticated amplifier circuit might be combined with a possible TrinTheremin Arduino library to keep the software simplicity of ToneAC while improving quality and GREATLY improving efficiency (battery life would be improved immensely).
- A voltage divider circuit -- this is one of the easiest (and also most helpful) changes that could be introduced in future versions. Essentially this would take the voltage of the battery, divide it in two (9v becomes 4.5, 7 becomes 3.5, etc), and feed it to an analog input (0v-5v yields a 0-1023 reading) on the microcontroller. This would allow the programmer to measure the voltage of the battery. With this they could create an integrated battery life check that would alert the user if the battery were low.
- Headphone jack -- a headphone jack could be added to the board in addition to the speaker so the user could play with headphones on. The port would have a switch in it that would be connected to a digital pin so the programmer could automatically turn off the speaker when headphones are plugged in.
- Reduced cost -- right now the TrinTheremin costs about 25$ per board to produce, however with hardware changes and different production methods, this could potentially be significantly reduced. For reference an Arduino Micro costs about 22$ (with no inputs or outputs built in)
- Expanded documentation and a more seamless user interface -- maybe a website? -- Right now trintherem.in redirects to this github repository, however in the future a website dedicated to the TrinTheremin could be produced.

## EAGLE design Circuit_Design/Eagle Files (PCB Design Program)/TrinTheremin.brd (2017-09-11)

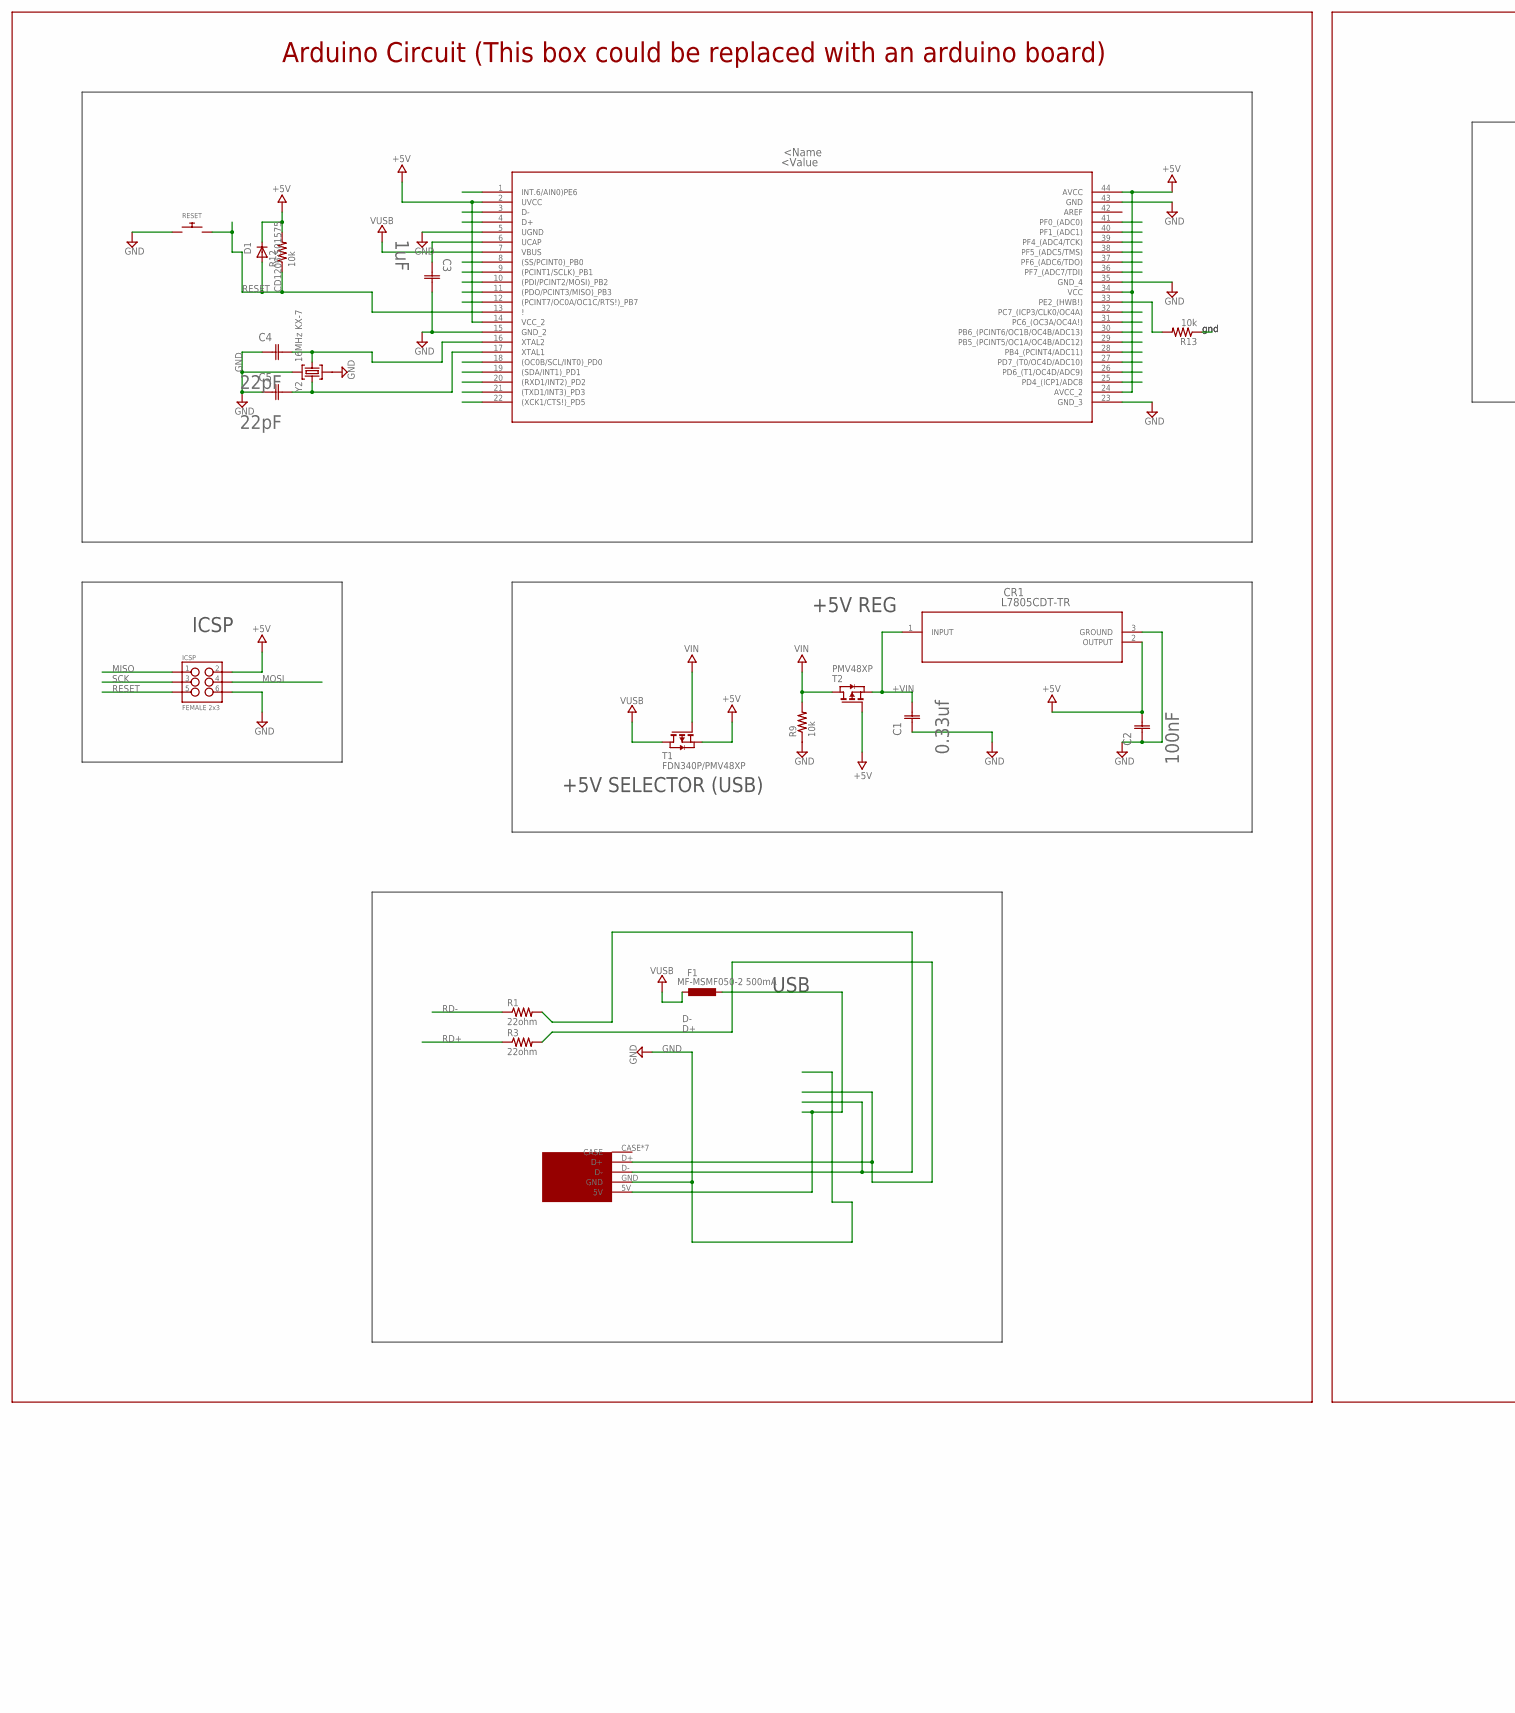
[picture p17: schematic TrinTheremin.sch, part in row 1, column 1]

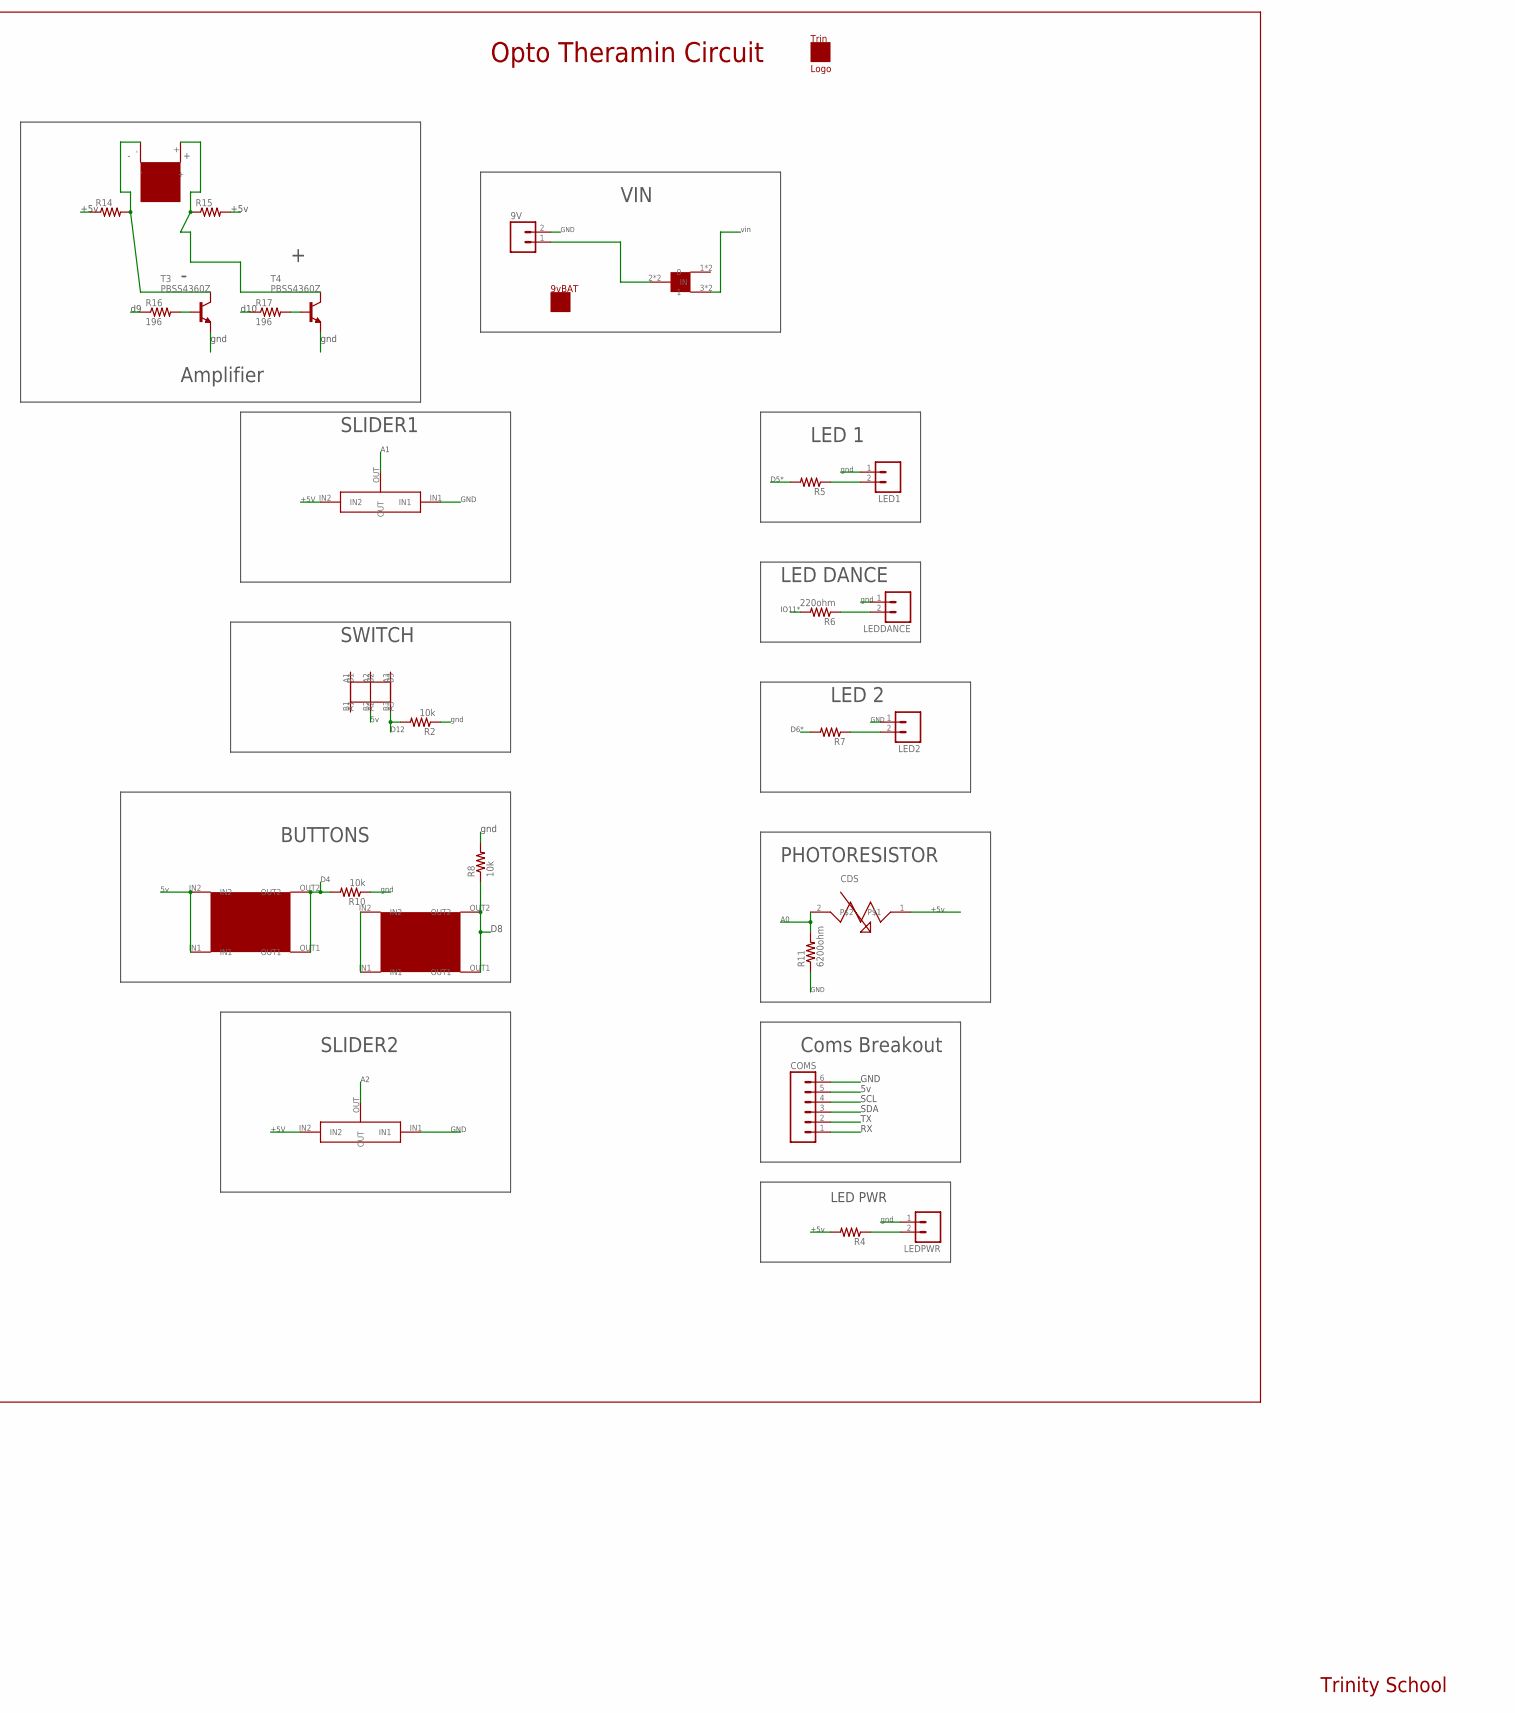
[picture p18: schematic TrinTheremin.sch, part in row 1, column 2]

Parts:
9V: M02PTH; 1X02
C1: 0.33uf; CAPC2013X110N
C2: 100nF; CAPC2013X110N
C3: 1uF; CAPC1608X85N
C4, C5: 22pF; CAPC1608X85N
COMS: M06SILK_FEMALE_PTH; 1X06
CR1: L7805CDT-TR; DPAK
D1: CD1206-S01575; MINIMELF
F1: MF-MSMF050-2 500mA; L1812
ICSP: FEMALE 2x3; 2X3
LED1, LED2: M02PTH; 1X02
LEDDANCE: M02PTH; 1X02
LEDPWR: M02PTH; 1X02
R1, R3: 22ohm; R0603
R2, R8, R9, R10, R12, R13: 10k; 0603-RES
R4, R5, R7: RESISTOR0603; 0603-RES
R6: 220ohm; 0603-RES
R11: 6200ohm; 0603-RES
R14, R15: R-US_R2512; R2512
R16, R17: 196; 1206
RESET: SWITCH_PUSHBUTTONC&K_KSS; BTN_CK_KSS
T1: FDN340P/PMV48XP; SOT-23
T2: PMV48XP; SOT-23
T3, T4: PBSS4360Z; SOT223
U$3: ATMEGA32U4-AU; 44ML
U$8: PWRSWITCHTHRU
U$9: CDS
U$10, U$14: DIGISLIDER
U$11: DIGISWITCH
U$13, U$17: BUT97
U$15: 9VBATHOLDERTALL
U$16: TRIN
U$20: GOODSPEAKER
U$23: MICROUSB
Y2: 16MHz KX-7; CRYSTAL-3.2-2.5

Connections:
+5V: C2.2 (C2), COMS.5, CR1.2 (OUTPUT), D1.C, ICSP.2, R4.2, R12.2, R14.1, R15.2, T1.2 (S), T2.3 (G), U$3.2 (UVCC), U$3.14 (VCC_2), U$3.24 (AVCC_2), U$3.34 (VCC), U$3.44 (AVCC), U$9.1, U$10.IN2, U$11.B2, U$13.IN1, U$13.IN2, U$14.IN2, U$17.IN1, U$17.IN2
+VIN: C1.2 (C2), CR1.1 (INPUT), T2.2 (S)
A0: R11.2, U$3.36 (PF7_(ADC7/TDI)), U$9.2
A1: U$3.37 (PF6_(ADC6/TDO)), U$10.OUT
A2: U$3.38 (PF5_(ADC5/TMS)), U$14.OUT
A3: U$3.39 (PF4_(ADC4/TCK))
A4: U$3.40 (PF1_(ADC1))
A5: U$3.41 (PF0_(ADC0))
BASE: R16.2, T3.1 (B)
COL: R14.2, T3.2 (C), T3.4 (C), U$20.-
D0/RX: COMS.1, U$3.20 ((RXD1/INT2)_PD2)
D1/TX: COMS.2, U$3.21 ((TXD1/INT3)_PD3)
D2/SDA: COMS.3, U$3.19 ((SDA/INT1)_PD1)
D3/SCL: COMS.4, U$3.18 ((OC0B/SCL/INT0)_PD0)
D4*: R10.2, U$3.25 (PD4_(ICP1/ADC8), U$13.OUT1, U$13.OUT2
D5*: R5.2, U$3.31 (PC6_(OC3A/OC4A!))
D6*: R7.2, U$3.27 (PD7_(T0/OC4D/ADC10))
D7: U$3.1 (INT.6/AIN0)PE6)
D+: R3.2, U$23.D+
D-: R1.2, U$23.D-
GND: 9V.2, C1.1 (C1), C2.1 (C1), C3.2 (C2), C4.1 (C1), C5.1 (C1), COMS.6, CR1.3 (GROUND), ICSP.6, LED1.1, LED2.1, LEDDANCE.1, LEDPWR.1, R2.1, R8.2, R9.1, R10.1, R11.1, R13.1, RESET.P$1, T3.3 (E), T4.3 (E), U$3.5 (UGND), U$3.15 (GND_2), U$3.23 (GND_3), U$3.35 (GND_4), U$3.43 (GND), U$10.IN1, U$14.IN1, U$23.GND, Y2.2 (GND), Y2.4 (GND)
HWB: R13.2, U$3.33 (PE2_(HWB!))
IO8: R8.1, U$3.28 (PB4_(PCINT4/ADC11)), U$17.OUT1, U$17.OUT2
IO9*: R16.1, U$3.29 (PB5_(PCINT5/OC1A/OC4B/ADC12))
IO10*: R17.1, U$3.30 (PB6_(PCINT6/OC1B/OC4B/ADC13))
IO11*: R6.2, U$3.12 ((PCINT7/OC0A/OC1C/RTS!)_PB7)
IO12*: R2.2, U$3.26 (PD6_(T1/OC4D/ADC9)), U$11.B3
IO13*: U$3.32 (PC7_(ICP3/CLK0/OC4A))
MISO: ICSP.1, U$3.11 ((PDO/PCINT3/MISO)_PB3)
MOSI: ICSP.4, U$3.10 ((PDI/PCINT2/MOSI)_PB2)
unnamed: LED1.2, R5.1
unnamed: R17.2, T4.1 (B)
unnamed: C3.1 (C1), U$3.6 (UCAP)
unnamed: R15.1, T4.2 (C), T4.4 (C), U$20.+
unnamed: LEDDANCE.2, R6.1
unnamed: LED2.2, R7.1
unnamed: 9V.1, U$8.2 (IN), U$8.5 (IN)
unnamed: LEDPWR.2, R4.1
RAWUSB: F1.1, U$23.5V
RD+: R3.1, U$3.4 (D+)
RD-: R1.1, U$3.3 (D-)
RESET: D1.A, ICSP.5, R12.1, RESET.P$2, U$3.13 (!)
RXLED/SS: U$3.8 ((SS/PCINT0)_PB0)
SCK: ICSP.3, U$3.9 ((PCINT1/SCLK)_PB1)
TXLED: U$3.22 ((XCK1/CTS!)_PD5)
VIN: R9.2, T1.3 (G), T2.1 (D), U$8.3 (1), U$8.6 (1)
VUSB: F1.2, T1.1 (D), U$3.7 (VBUS)
XTAL3: C4.2 (C2), U$3.16 (XTAL2), Y2.1 (C1)
XTAL4: C5.2 (C2), U$3.17 (XTAL1), Y2.3 (C2)

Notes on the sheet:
+5V REG
ICSP
USB
+5V SELECTOR (USB)
CDS
GND
gnd
Arduino Circuit (This box could be replaced with an arduino board)
Opto Theramin Circuit
Trinity School
LED 2
LED DANCE
Coms Breakout
PHOTORESISTOR
LED 1
+5v
VIN
SWITCH
BUTTONS
SLIDER1
SLIDER2
vin
+5V
LED PWR
D5*
D6*
IO11*
D12
Amplifier
d10
SDA
SCL

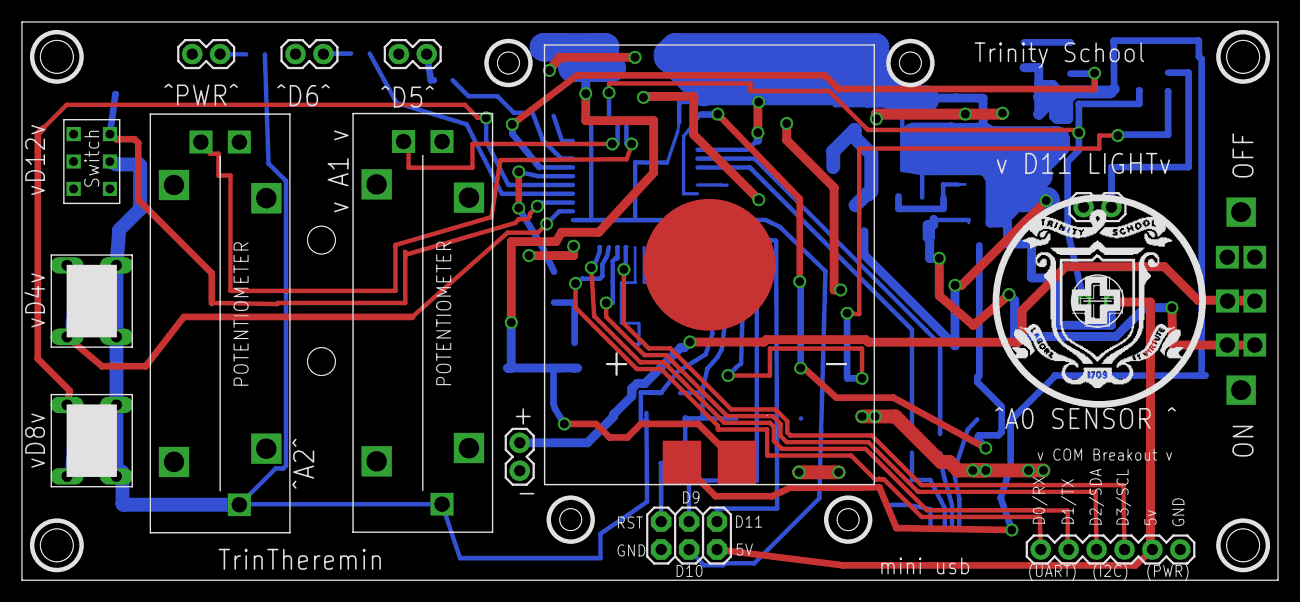
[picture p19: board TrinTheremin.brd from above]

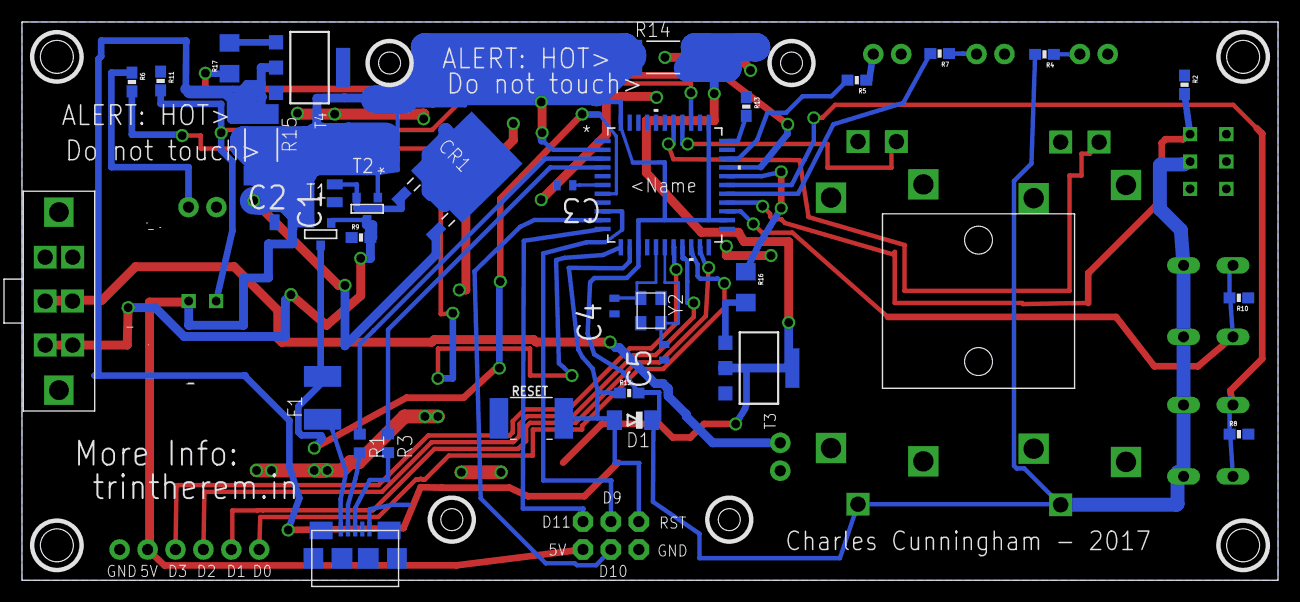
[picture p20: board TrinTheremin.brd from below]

Board: 2 copper layers, 114.3 x 50.8 mm, 50 parts (35 on the bottom side), 42 nets.

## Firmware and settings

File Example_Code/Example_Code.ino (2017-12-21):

/*
Example Code for the TrinTheremin
Written by Charles Cunningham in 2017
In assosiation with the Trinity School Computer Science department
Written for the TrinTheremin project, initial version (v1)
Visit for more info and resources for the TrinTheremin project:
www.trintherem.in
*/

//==================================================================
//==================================================================
//Libraries---------------------------------------------------------
#include <toneAC.h> //The speaker can be controlled with toneAC
//Reference: https://playground.arduino.cc/Code/ToneAC

//Pin Definitions---------------------------------------------------
//digital inputs
#define switchPin 12 //The switch is on digital pin 12
#define topButtonPin 4 //The top button is on digital pin 4
#define botButtonPin 8 //The bottom button is on digital pin 8
//analog inputs
#define leftSliderPin 2 //The left slider is on analog pin 2
#define rightSliderPin 1 //The right slider is on analog pin 1
#define lightSensorPin 0 //The light sensor is on analog pin 0
//digital or analog outputs
#define greenLedPin 6 //The green (left) led is on digital pin 6
#define blueLedPin 5 //The blue (right) led is on digital pin 5
#define danceLedPin 11 //The dancing led is on digital pin 11
/*When you define something in Arduino it replaces all references
to that constant with the defined value during code compilation
(under the hood).   Thus the defined value does not take up 
space on the Arduino as a variable or constant*/

//Scales

float scale1[]={391.995,440.0,493.883,587.330,659.255,783.991,880.0,987.767,1174.66,1318.51}; 
//top half- G major pent = E minor pent G4 A4 B4 D5 E5 G5 A5 B5 D6 E6

float scale2[]={130.813,146.832,164.814, 195.998, 220.000,261.626,293.665,329.628,391.995, 440.0}; 
//bottom half- C major pent = A minor pent C3 D3 E3 G3 A3 C4 D4 E4 G4 A4

float scale3[]={146.832,164.814,184.997,220.000,246.942,293.665,329.628,369.994,440.000, 493.883};
//bottom - play D major pent = B minor pent D3 E3 F#3 A3 B3 D4 E4 F#4 A4 B4

unsigned long ts=0L; //Counter to enact delays without breaking loop  
unsigned long ts2=0L; //Counter to enact delays without breaking loop
float maxReading=0; //Ambient sensor reading for calibration
float minReading=1024; //Average sensor reading when sensor is covered
boolean autoPlay=false; //Boolean autoplay toggle
boolean newAutoPlay=true; //Used for triggering a calibration every time the autoplay feature is switched on
int autoPlayAmbient=0; //The ambient value for the autoplay feature
int readings[5];      // the readings from the analog input
int total =0;
int readIndex = 0; 

//==============================SETUP===============================
void setup() {
  
  //configure inputs
  pinMode(switchPin,INPUT); //Set the switch as an input
  pinMode(topButtonPin,INPUT); //Set the bot button as an input
  pinMode(botButtonPin,INPUT); //Set the top button as an input
  //configure outputs
  pinMode(danceLedPin,OUTPUT); //Set the dancing LED as an output
  pinMode(blueLedPin,OUTPUT); //Set the blue LED as an output
  pinMode(greenLedPin,OUTPUT); //Set the green LED as an output

  
  //Calibration-------------------------------vvv------------------

  ts=millis(); //Start counter at current clock time
  while(millis()-ts<5000){ //While clock time - start time is < 5s
    int reading=analogRead(0); //Add current reading to avgReading
    if(reading > maxReading) maxReading = reading;
    else if (reading < minReading) minReading = reading;
    
    //Blue LED blinking to show ambient calibration in progress
    if(millis()%800 ==0){ //For the first 400 milliseconds:
      digitalWrite(blueLedPin,HIGH); //Blue light on
    }
    else if(millis()%400==0){ //For the second 400 milliseconds:
      digitalWrite(blueLedPin,LOW); //Blue LED off
    }
  }  
  
  digitalWrite(blueLedPin,LOW);
  digitalWrite(greenLedPin,LOW); //Set both LEDs to LOW to tell the user to put their hand over the sensor
 
  //Begin Startup Light Sequence----------------------vvv-----------------
  digitalWrite(greenLedPin,LOW);  //All lights off
  digitalWrite(blueLedPin,LOW);   
  delay(200);                     //Delay for 200ms
  digitalWrite(greenLedPin,HIGH); //Green light on
  delay(100);                     //Delay for 100ms
  digitalWrite(blueLedPin,HIGH);  //Blue light on
  delay(100);                     //Delay for 100ms
  digitalWrite(greenLedPin,LOW);
  digitalWrite(blueLedPin,LOW);   //All lights off
  delay(100);                     //Delay for 100ms
  digitalWrite(greenLedPin,HIGH); 
  digitalWrite(blueLedPin,HIGH);  //All lights on
  delay(200);                     //Delay for 200ms
  //End Startup Light Sequence--------------------^^^----------------
 
  Serial.begin(9600);

  for (int thisReading = 0; thisReading < 5; thisReading++) {
    readings[thisReading] = 0;
  }
}//setup()


void loop() {

  if(digitalRead(topButtonPin)==HIGH){
    autoPlay=true;
    digitalWrite(danceLedPin,HIGH); 
    if(newAutoPlay==true){ //Begin autoplay calibration
      double apReadings=0; //Declare/init variable to hold average ambient value for autoplay
      for(int i=0;i<20;i++){
        apReadings+=analogRead(lightSensorPin); //Add up readings
      }
      apReadings/=20; //Divide sum of readings by number of readings for average reading
      autoPlayAmbient=round(apReadings); //Round the floating point averaged variable to an int
      newAutoPlay=false; //Autoplay no longer needs calibration
    }
  } else{
    newAutoPlay=true; //If auoplay is turned off, arm the calibration feature for when it is turned back on
    autoPlay=false;
    digitalWrite(danceLedPin,LOW); 
  }

  if((digitalRead(switchPin)==HIGH)&&(digitalRead(botButtonPin)==LOW)){ //If the play switch is on and the pause button is off
      int scaleSliderVal=analogRead(leftSliderPin);

      if(scaleSliderVal<50) sound(scale1, -1);//top - play continuous notes
      else if(scaleSliderVal<575) sound(scale1, 10); //top half- G major pent = E minor pent GABDE
      else if (scaleSliderVal<1000) sound(scale2, 10 ); //bottom half- C major pent = A minor pent CDEGA
      else sound(scale3, 10 ); //bottom - play D major pent = B minor pent DEF#AB
  }
  else{ 
    noToneAC(); //Turn off speaker
    analogWrite(blueLedPin,LOW); 
  }//play switch is off
  
} //loop()


void sound(float thisScale[], int num_notes){
  int sensorValue = constrain(analogRead(lightSensorPin), minReading,maxReading);
    
  // subtract the last reading:
  total = total - readings[readIndex];
  // read from the sensor:
  readings[readIndex] = sensorValue;
  // add the reading to the total:
  total = total + readings[readIndex];
  // advance to the next position in the array:
  readIndex = readIndex + 1;

  // if we're at the end of the array...
  if (readIndex >= 5) {
    // ...wrap around to the beginning:
    readIndex = 0;
  }

  // calculate the average:
  int averageValue = total / 5;
  
  if (num_notes > 0){
    
    int closestPos=0;
    
    if (autoPlay==false) closestPos= map(constrain(sensorValue,minReading,maxReading),minReading,maxReading,0,num_notes-1);  
    else closestPos= map(averageValue,autoPlayAmbient,autoPlayAmbient+550-round(0.5*(double)autoPlayAmbient),0,num_notes-1); //Autoplay, so notes optimized for autoplay, depending on calibrated ambient autoplay value
  
    int volVal=map(analogRead(rightSliderPin),0,1000,1,10); //The map HAS TO BE from 0 to 1000 or the sound quality will be bad at full volume

    toneAC(thisScale[closestPos],volVal);
    analogWrite(blueLedPin, map(thisScale[closestPos],110,1760 ,0,255)); //Sets blue LED intensity proportional to the current note
  
  }//quantized note from one of the predefined scales
  else{
    
    int volVal=map(analogRead(rightSliderPin),0,1000,1,10); //The map HAS TO BE from 0 to 1000 or the sound quality will be bad at full volume
    double note = constrain(map(averageValue,minReading,maxReading,130, 1300), 130, 1300); 
    toneAC(note,volVal);
    analogWrite(blueLedPin, map(note,110,1760 ,0,255)); //Sets blue LED intensity proportional to the current note
  
  }//continuous, non-chromatic note
  
}//sound()

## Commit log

2017-09-11 Added design files... literature in development.
    To do: datasheet, readme, possibly different 3d design formats?
    [CaseTopExample.SLDPRT, CaseTopExample.STL, CaseTopSketch.SLDPRT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]
2017-09-11 Added missing files
    [HornBase.STL, HornExample.STL]
2017-09-11 Renamed Folders
    [CaseTopExample.SLDPRT, CaseTopExample.STL, CaseTopSketch.SLDPRT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]
2017-09-12 Misc. Changes... see details
    Added circuit design pictures, fixed horn (reversed), changed solidworks
    files to display PCB below part, added datasheet (in progress), changed
    folder names, reorganized
    [CaseTopExample.SLDPRT, CaseTopExample.STL, CaseTopSketch.SLDPRT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]
2017-12-03 Added Horn MK2
    [HornExampleMK1.SLDPRT, HornExampleMK1.STL, HornExampleMK2.STL]
2017-12-03 Changed Horn
    [HornExampleMK2.STL]
2017-12-21 Changed folder names and consolidated example codes
    [TrinTheremin.brd, TrinTheremin.sch]

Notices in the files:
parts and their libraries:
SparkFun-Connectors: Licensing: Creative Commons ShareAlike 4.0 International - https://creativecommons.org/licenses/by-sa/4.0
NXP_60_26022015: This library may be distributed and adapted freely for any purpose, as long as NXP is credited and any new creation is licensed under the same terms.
